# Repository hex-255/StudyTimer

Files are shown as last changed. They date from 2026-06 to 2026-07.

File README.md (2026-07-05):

# StudyTimer
study timer with neopixel feedback and adaptive break time calculation

study for amount of time you decide and get break time allotted accordingly. 

break time = time studied divided by 5

formfactor inspired by [Adafruit NeoPixel rotary fidget](https://learn.adafruit.com/neopixel-rotary-fidget/overview) 

Check out the the [Instructables article](https://www.instructables.com/MagSafe-StudyTimer-Makes-Studying-3-More-Enjoyable/) for an in-depth build guide.

## Features
- Neopixel visual feedback (one pixel equals 2.5 minutes of study time or 1 minute of breaktime)
- Adaptive break time calculation
- Audio feedback with mini speaker
- interface through [Adafruit ANO Rotary Encoder](https://learn.adafruit.com/ano-rotary-encoder)



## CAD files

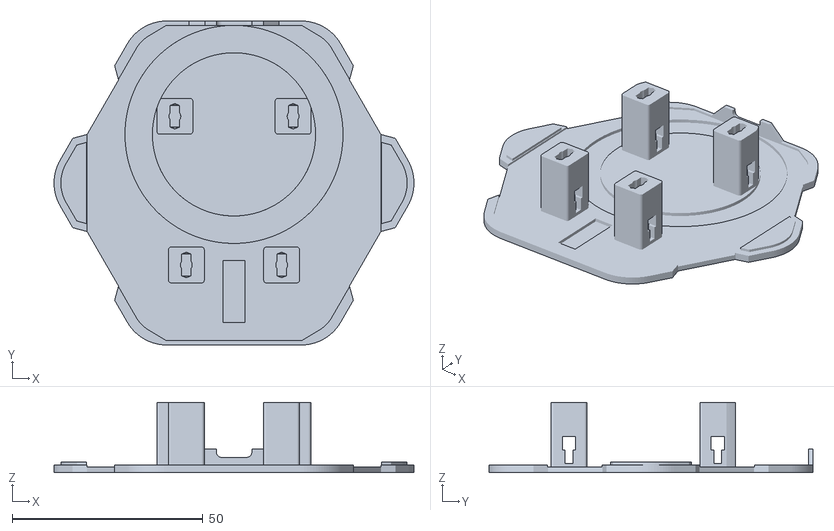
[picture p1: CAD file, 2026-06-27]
STL_files/Bottom.stl
94.4 x 85.0 x 18.4

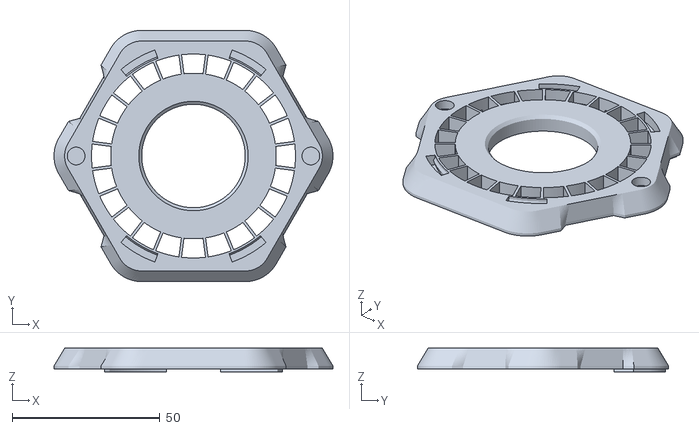
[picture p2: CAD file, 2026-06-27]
STL_files/Top.stl
94.4 x 85.0 x 8.00

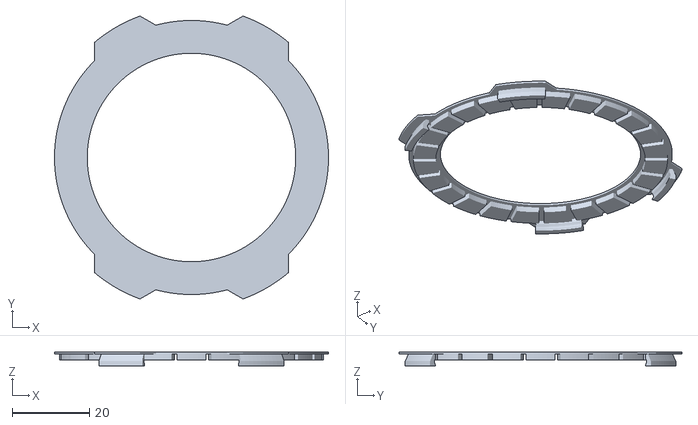
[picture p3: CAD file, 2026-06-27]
STL_files/Diffuser.stl
71.0 x 73.3 x 3.50

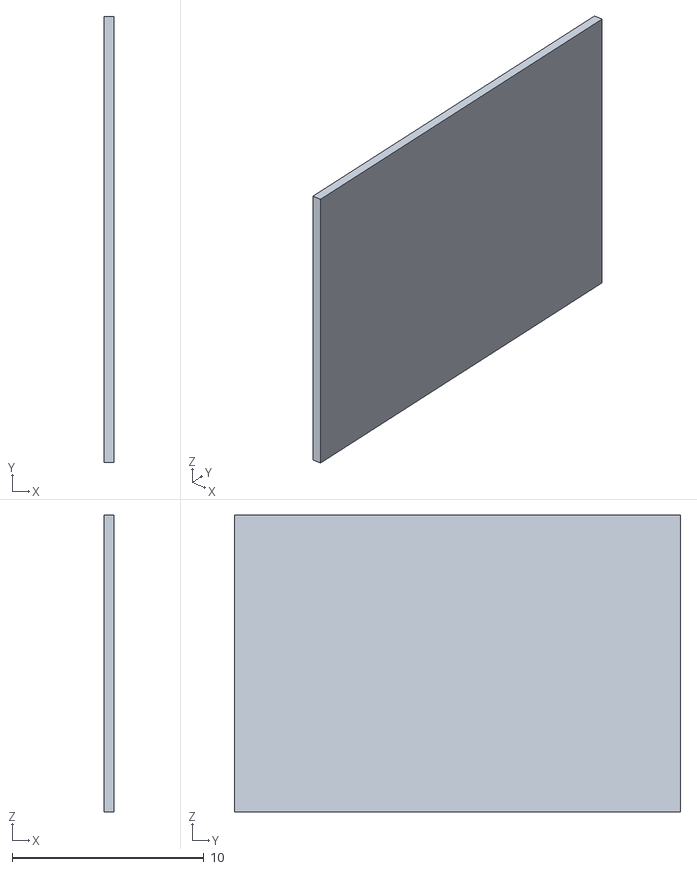
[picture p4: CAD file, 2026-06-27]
STL_files/Streak_Cover_Flat.stl
0.5 x 23.3 x 15.5

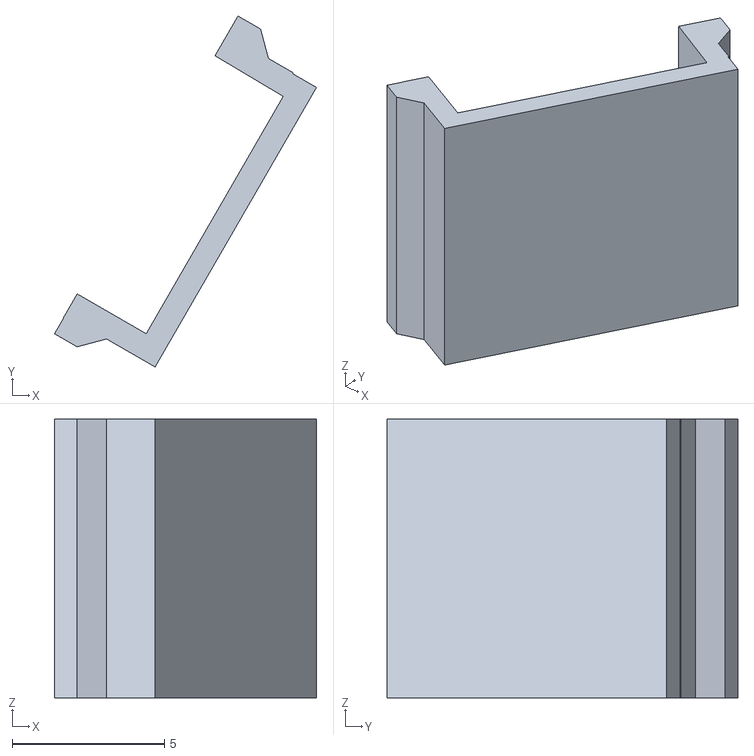
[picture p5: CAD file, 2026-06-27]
STL_files/SlideSwitch_White.stl
8.60 x 11.5 x 9.15

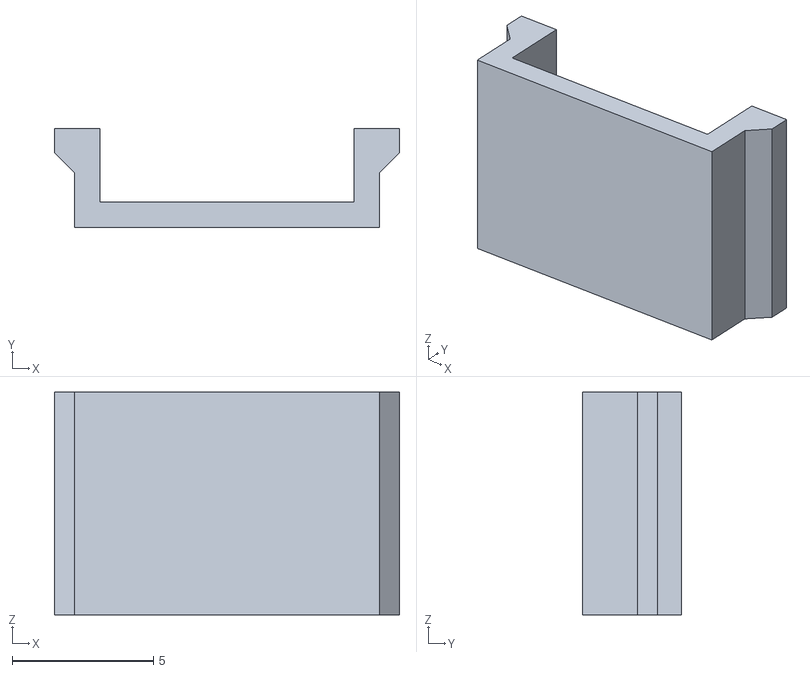
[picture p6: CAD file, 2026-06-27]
STL_files/Magnet_White.stl
12.2 x 3.51 x 7.89

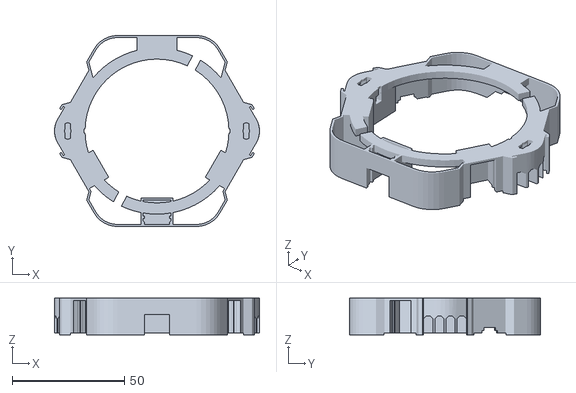
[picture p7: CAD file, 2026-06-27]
STL_files/Middle.stl
91.2 x 85.0 x 16.4

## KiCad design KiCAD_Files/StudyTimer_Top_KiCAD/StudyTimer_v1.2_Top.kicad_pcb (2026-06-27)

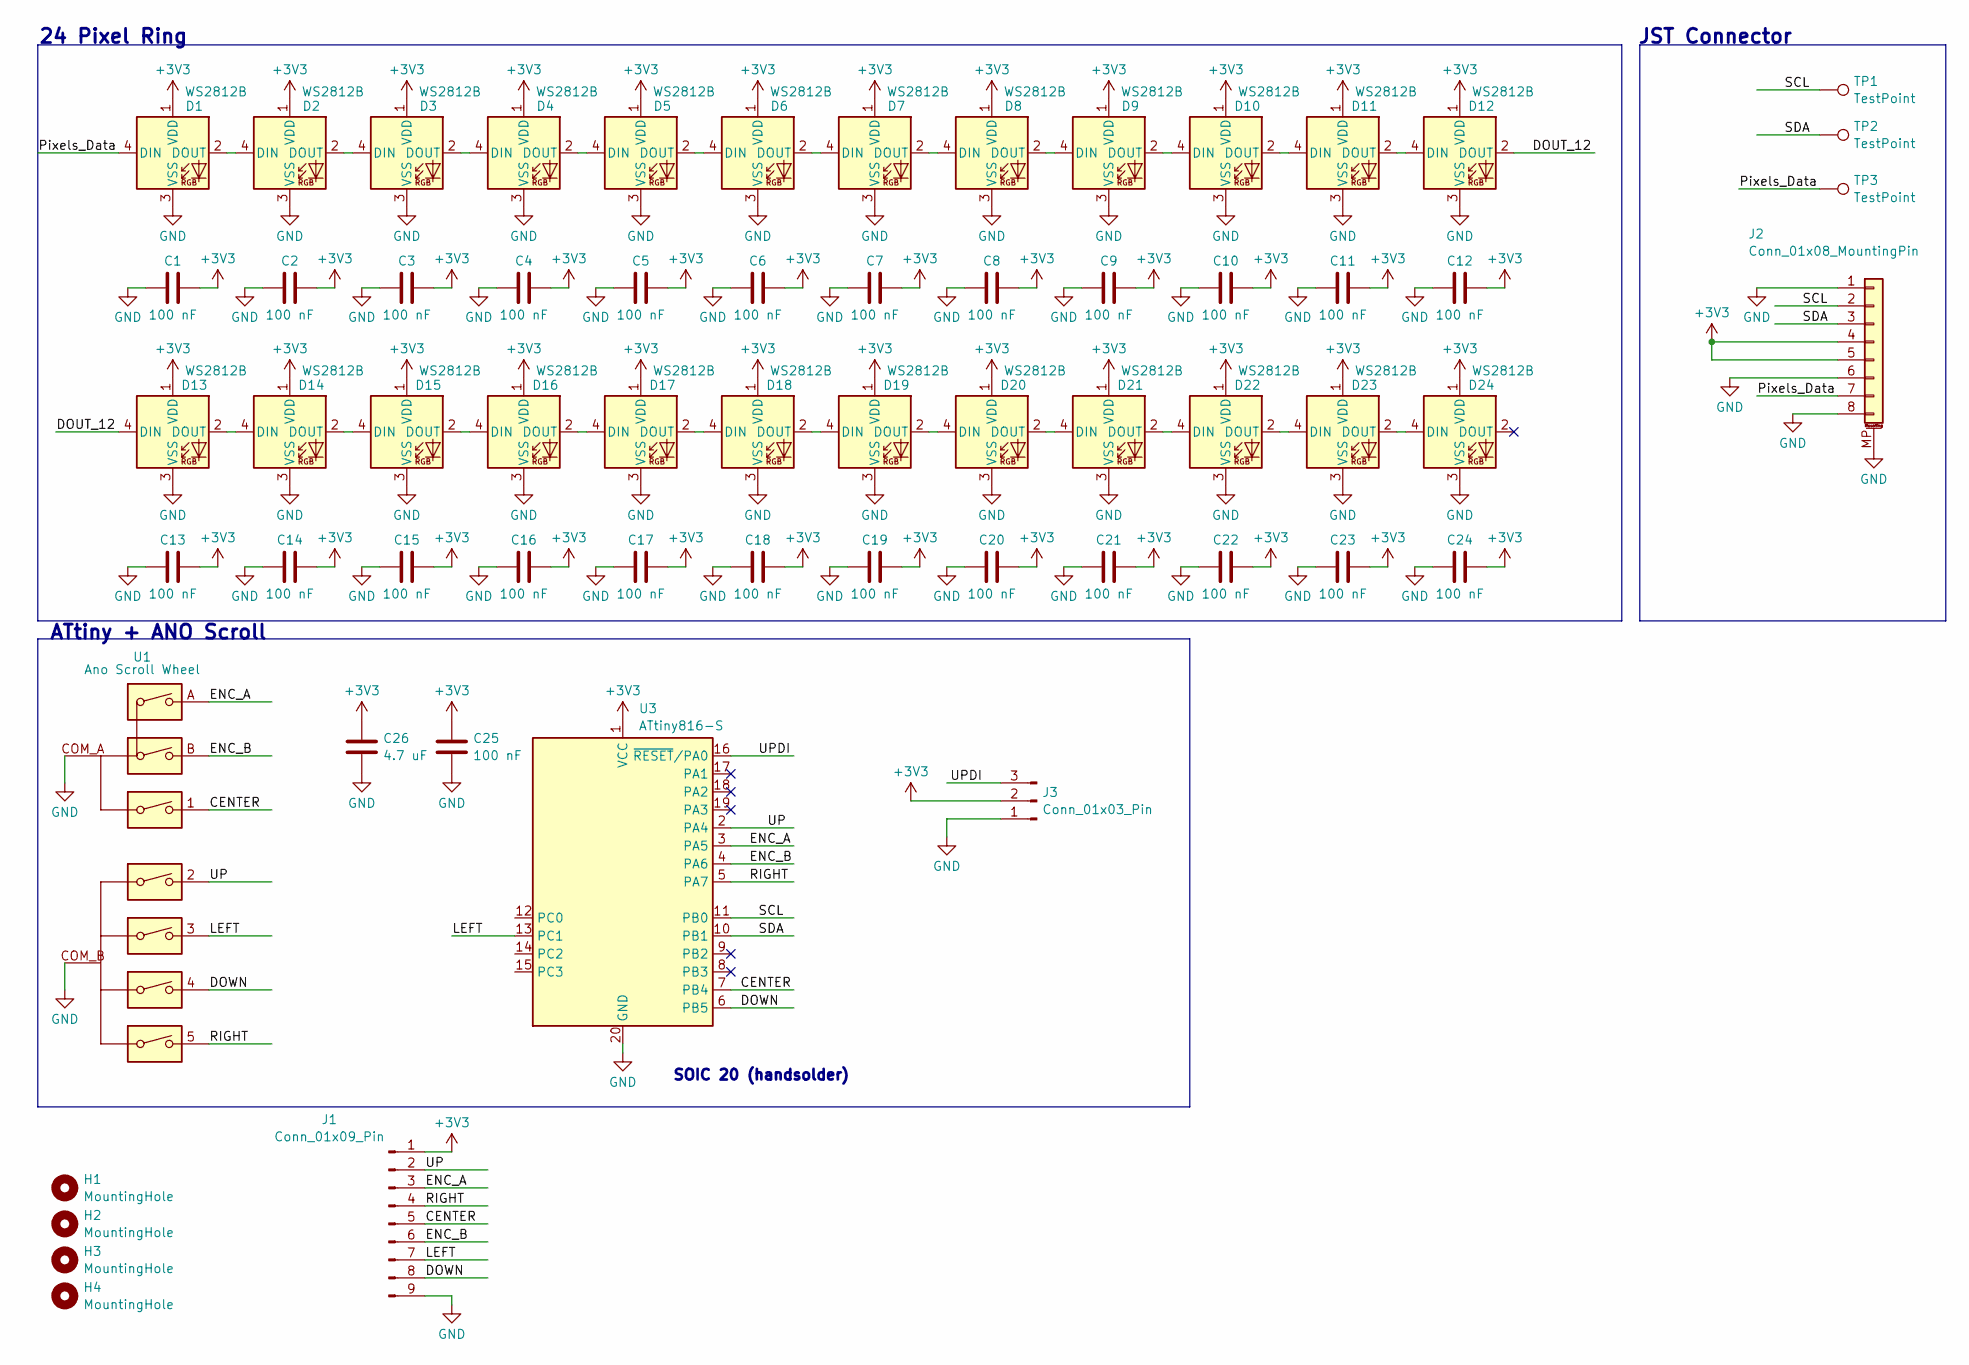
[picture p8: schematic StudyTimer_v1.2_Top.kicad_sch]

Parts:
C1, C2, C3, C4, C5, C6, C7, C8, C9, C10, C11, C12, C13, C14, C15, C16, C17, C18, C19, C20, C21, C22, C23, C24, C25: 100 nF; C_0805_2012Metric_Pad1.18x1.45mm_HandSolder
C26: 4.7 uF; C_0805_2012Metric_Pad1.18x1.45mm_HandSolder
D1: WS2812B; LED_WS2812B_PLCC4_5.0x5.0mm_P3.2mm_edited; Manufacturer_Part_Number 3094
D2, D3, D4, D5, D6, D7, D8, D9, D10, D11, D12, D13, D14, D15, D16, D17, D18, D19, D20, D21, D22, D23, D24: WS2812B; LED_WS2812B_PLCC4_5.0x5.0mm_P3.2mm_edited
H1, H2, H3, H4: MountingHole; MountingHole_3.2mm_M3
J1: Conn_01x09_Pin; PinHeader_1x09_P2.54mm_Vertical
J2: Conn_01x08_MountingPin; SM08BSRSSTBLFSN_1mm_8Pin; Manufacturer_Part_Number SM08B-SRSS-TB
J3: Conn_01x03_Pin; PinHeader_1x03_P2.54mm_Vertical
TP1, TP2, TP3: TestPoint; TestPoint_THTPad_D2.0mm_Drill1.0mm
U1: Ano Scroll Wheel; ANO Scroll Wheel; Manufacturer_Part_Number 5001
U3: ATtiny816-S; SOIC-20W_7.5x12.8mm_P1.27mm; Manufacturer_Part_Number ATTINY816-SNR

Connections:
+3V3: C1.2, C2.2, C3.2, C4.2, C5.2, C6.2, C7.2, C8.2, C9.2, C10.2, C11.2, C12.2, C13.2, C14.2, C15.2, C16.2, C17.2, C18.2, C19.2, C20.2, C21.2, C22.2, C23.2, C24.2, C25.1, C26.1, D1.1 (VDD), D2.1 (VDD), D3.1 (VDD), D4.1 (VDD), D5.1 (VDD), D6.1 (VDD), D7.1 (VDD), D8.1 (VDD), D9.1 (VDD), D10.1 (VDD), D11.1 (VDD), D12.1 (VDD), D13.1 (VDD), D14.1 (VDD), D15.1 (VDD), D16.1 (VDD), D17.1 (VDD), D18.1 (VDD), D19.1 (VDD), D20.1 (VDD), D21.1 (VDD), D22.1 (VDD), D23.1 (VDD), D24.1 (VDD), J1.1, J2.4, J2.5, J3.2, U3.1 (VCC)
/CENTER: J1.5, U1.1, U3.7 (PB4)
/DOUT_12: D12.2 (DOUT), D13.4 (DIN)
/DOWN: J1.8, U1.4, U3.6 (PB5)
/ENC_A: J1.3, U1.A, U3.3 (PA5)
/ENC_B: J1.6, U1.B, U3.4 (PA6)
/LEFT: J1.7, U1.3, U3.13 (PC1)
/Pixels_Data: D1.4 (DIN), J2.7, TP3.1
/RIGHT: J1.4, U1.5, U3.5 (PA7)
/SCL: J2.2, TP1.1, U3.11 (PB0)
/SDA: J2.3, TP2.1, U3.10 (PB1)
/UP: J1.2, U1.2, U3.2 (PA4)
/UPDI: J3.3, U3.16 (~RESET/PA0)
GND: C1.1, C2.1, C3.1, C4.1, C5.1, C6.1, C7.1, C8.1, C9.1, C10.1, C11.1, C12.1, C13.1, C14.1, C15.1, C16.1, C17.1, C18.1, C19.1, C20.1, C21.1, C22.1, C23.1, C24.1, C25.2, C26.2, D1.3 (VSS), D2.3 (VSS), D3.3 (VSS), D4.3 (VSS), D5.3 (VSS), D6.3 (VSS), D7.3 (VSS), D8.3 (VSS), D9.3 (VSS), D10.3 (VSS), D11.3 (VSS), D12.3 (VSS), D13.3 (VSS), D14.3 (VSS), D15.3 (VSS), D16.3 (VSS), D17.3 (VSS), D18.3 (VSS), D19.3 (VSS), D20.3 (VSS), D21.3 (VSS), D22.3 (VSS), D23.3 (VSS), D24.3 (VSS), J1.9, J2.1, J2.6, J2.8, J2.MP (MountPin), J3.1, U1.COM_A, U1.COM_B, U3.20 (GND)
unnamed: D1.2 (DOUT), D2.4 (DIN)
unnamed: D2.2 (DOUT), D3.4 (DIN)
unnamed: D3.2 (DOUT), D4.4 (DIN)
unnamed: D4.2 (DOUT), D5.4 (DIN)
unnamed: D5.2 (DOUT), D6.4 (DIN)
unnamed: D6.2 (DOUT), D7.4 (DIN)
unnamed: D7.2 (DOUT), D8.4 (DIN)
unnamed: D8.2 (DOUT), D9.4 (DIN)
unnamed: D9.2 (DOUT), D10.4 (DIN)
unnamed: D10.2 (DOUT), D11.4 (DIN)
unnamed: D11.2 (DOUT), D12.4 (DIN)
unnamed: D13.2 (DOUT), D14.4 (DIN)
unnamed: D14.2 (DOUT), D15.4 (DIN)
unnamed: D15.2 (DOUT), D16.4 (DIN)
unnamed: D16.2 (DOUT), D17.4 (DIN)
unnamed: D17.2 (DOUT), D18.4 (DIN)
unnamed: D18.2 (DOUT), D19.4 (DIN)
unnamed: D19.2 (DOUT), D20.4 (DIN)
unnamed: D20.2 (DOUT), D21.4 (DIN)
unnamed: D21.2 (DOUT), D22.4 (DIN)
unnamed: D22.2 (DOUT), D23.4 (DIN)
unnamed: D23.2 (DOUT), D24.4 (DIN)

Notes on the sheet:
ATtiny + ANO Scroll
JST Connector
SOIC 20 (handsolder)
24 Pixel Ring

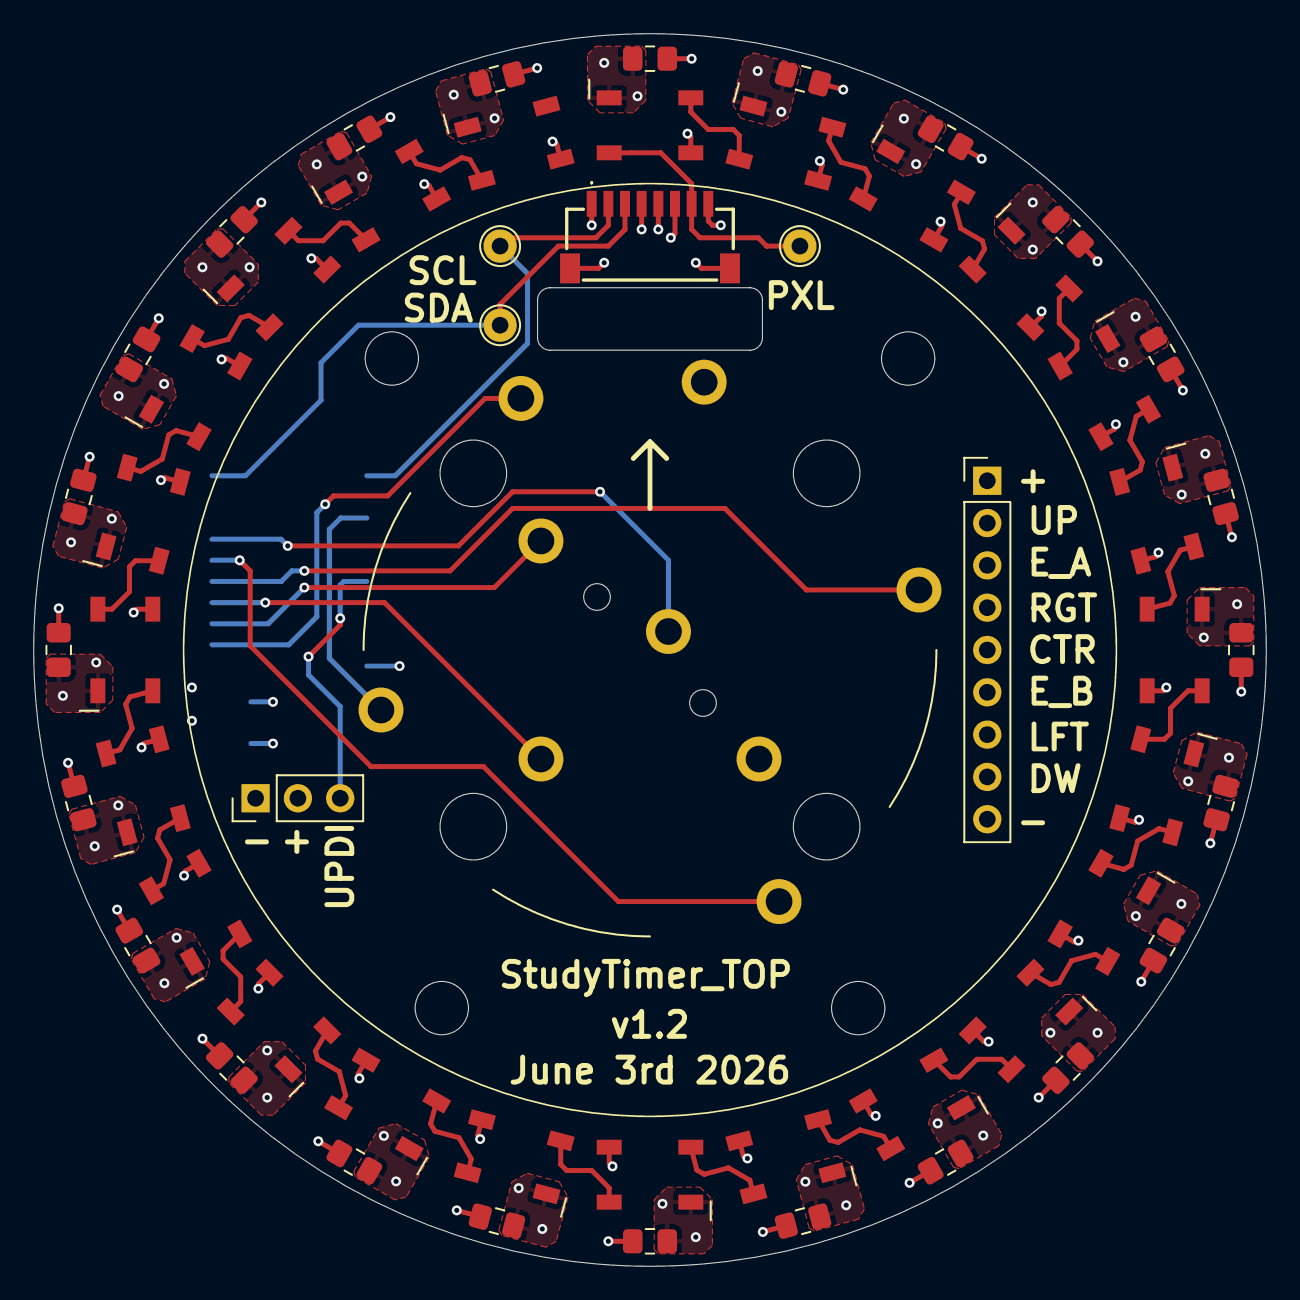
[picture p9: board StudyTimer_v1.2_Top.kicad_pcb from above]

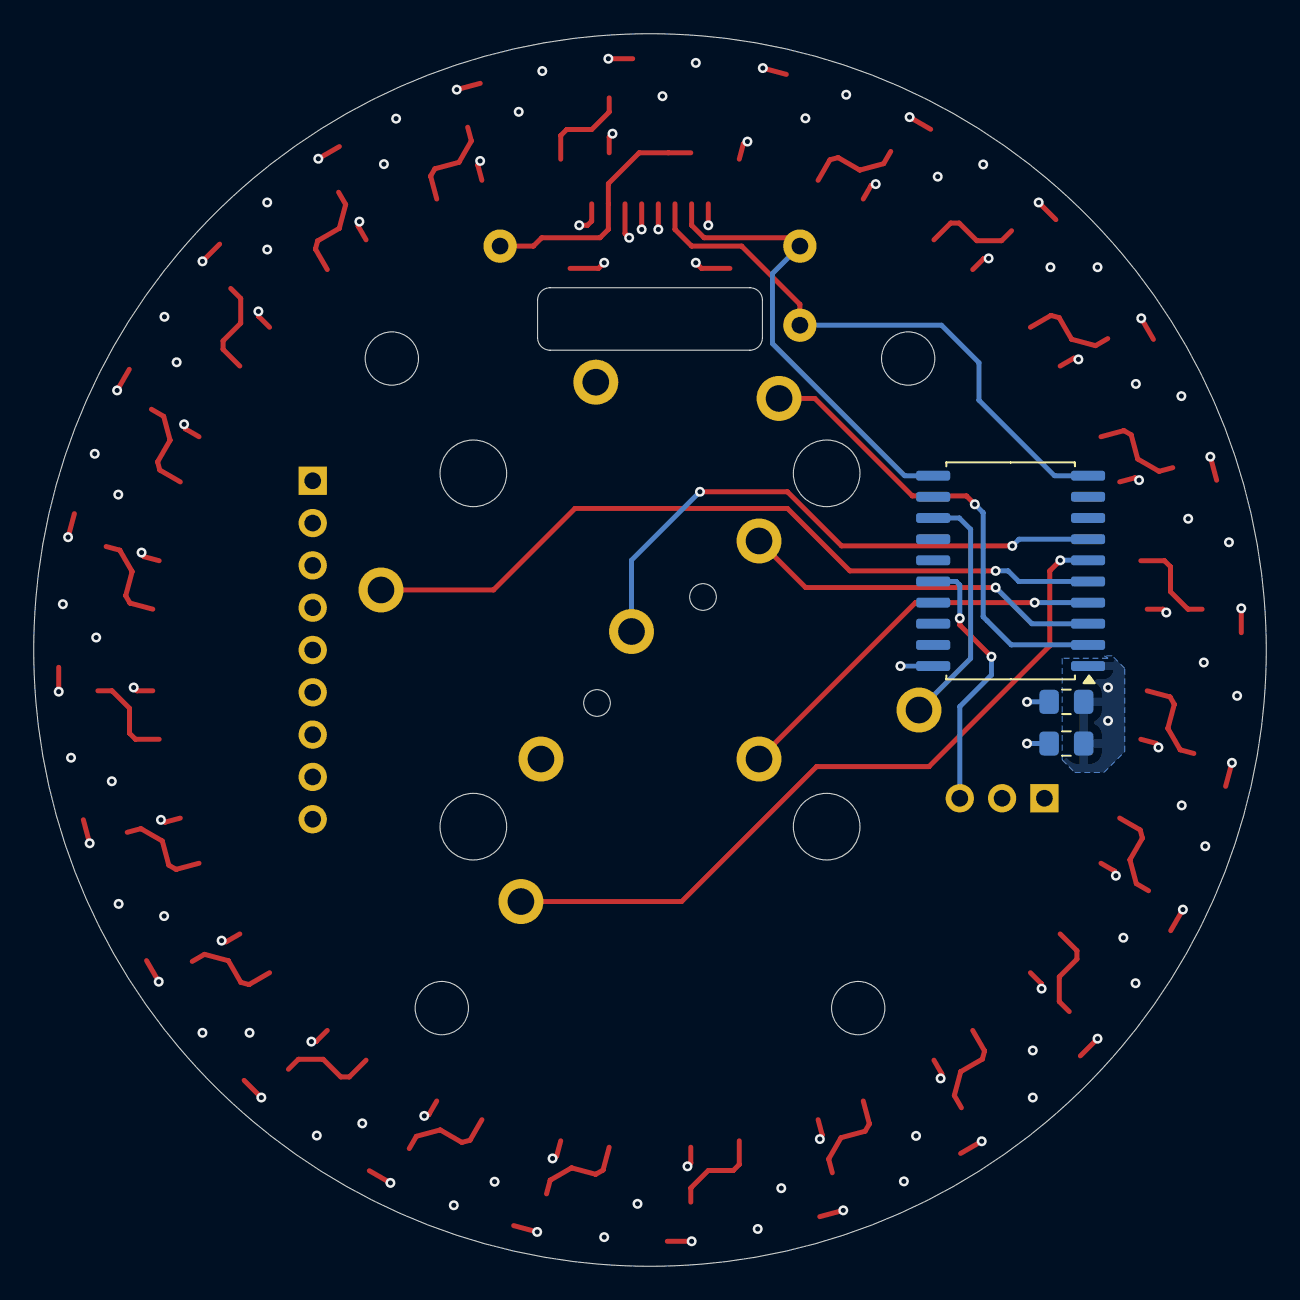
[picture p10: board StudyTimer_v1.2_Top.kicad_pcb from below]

Board: 4 copper layers, 74.0 x 74.0 mm, 62 parts (3 on the bottom side), 36 nets.

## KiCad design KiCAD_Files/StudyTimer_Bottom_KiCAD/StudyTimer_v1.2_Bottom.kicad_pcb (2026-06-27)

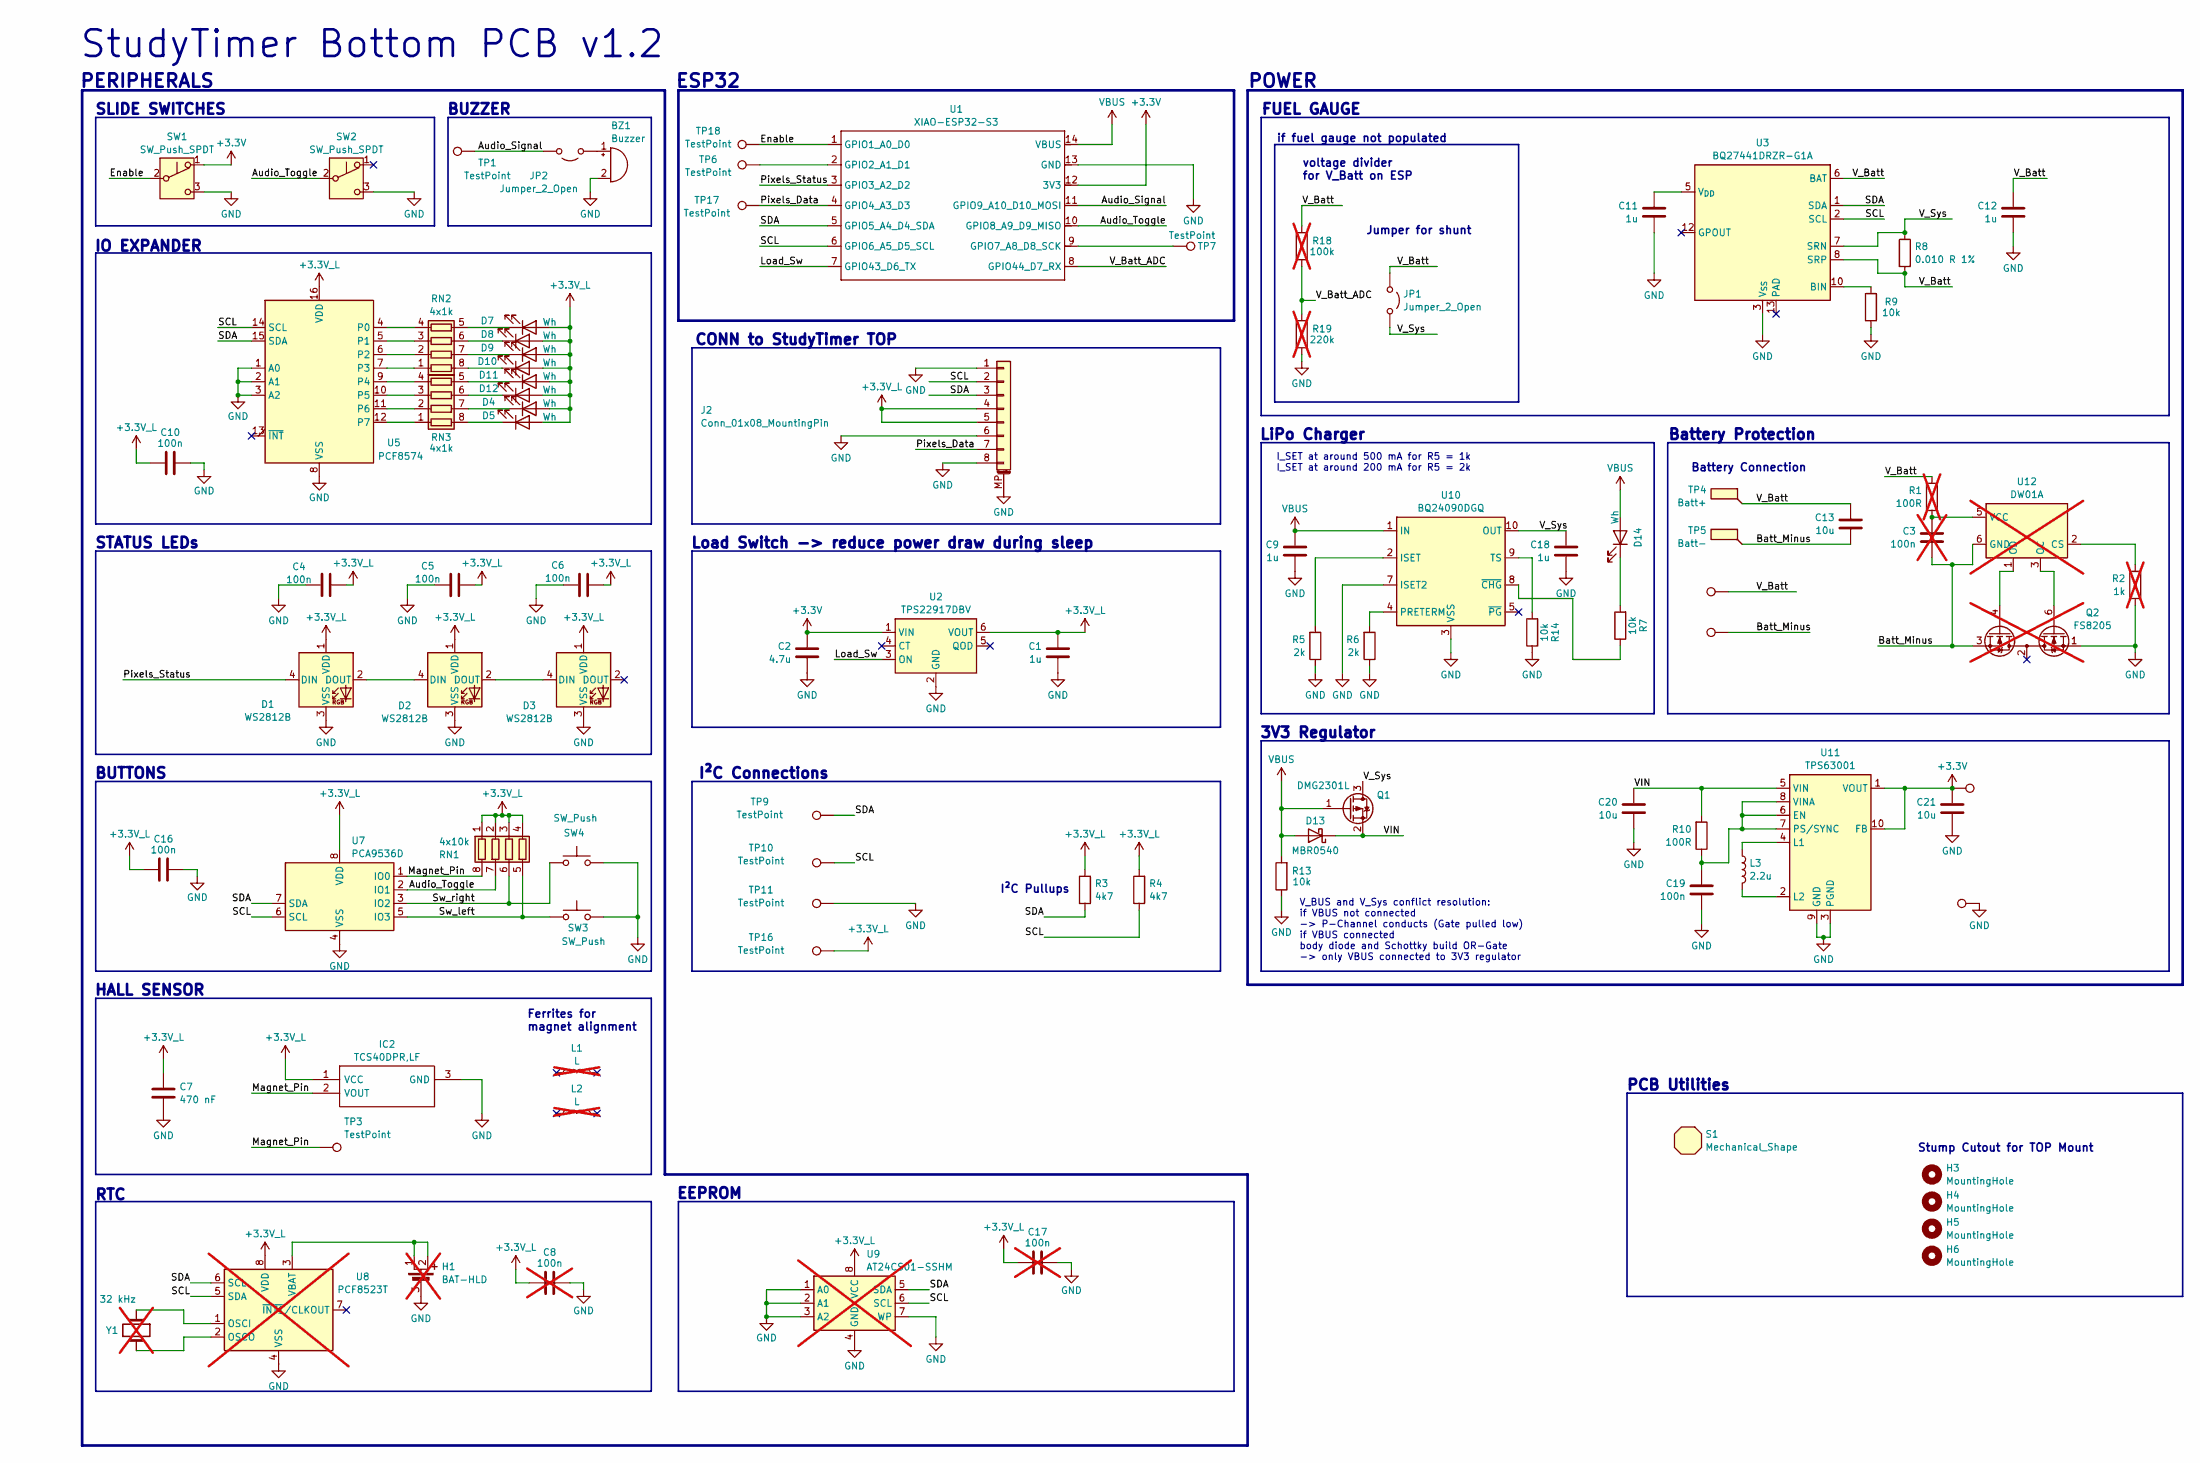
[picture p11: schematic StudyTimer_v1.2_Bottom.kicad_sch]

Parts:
BZ1: Buzzer; Buzzer_CUI_CPT-9019S-SMT; Manufacturer_Part_Number CPT-9019S-SMT-TR
C1, C9, C11, C12, C18: 1u; C_0805_2012Metric_Pad1.18x1.45mm_HandSolder
C2: 4.7u; C_0805_2012Metric_Pad1.18x1.45mm_HandSolder
C3, C8, C17: 100n; C_0805_2012Metric_Pad1.18x1.45mm_HandSolder; not fitted
C4, C5, C6, C10, C16, C19: 100n; C_0805_2012Metric_Pad1.18x1.45mm_HandSolder
C7: 470 nF; C_0805_2012Metric_Pad1.18x1.45mm_HandSolder
C13, C20, C21: 10u; C_0805_2012Metric_Pad1.18x1.45mm_HandSolder
D1, D2, D3: WS2812B; LED_WS2812B_PLCC4_5.0x5.0mm_P3.2mm
D4, D5, D8, D9, D10, D11, D12, D14: Wh; LED_0805_2012Metric_Pad1.15x1.40mm_HandSolder
D7: Wh; LED_0805_2012Metric_Pad1.15x1.40mm_HandSolder; Manufacturer_Part_Number IN-S85AT5UW
D13: MBR0540; D_SOD-123
H1: BAT-HLD; BATHLD007SMTTR; Manufacturer_Part_Number BAT-HLD-003-SMT; Mouser Part Number 712-BAT-HLD-003-SMT; not fitted
H3, H4, H5, H6: MountingHole; StudyTimer_Stump_Cutout
IC2: TCS40DPR,LF; SOTFL95P240X88-3N; Manufacturer_Part_Number TCS40DPR,LF; Mouser Part Number 757-TCS40DPRLF
J2: Conn_01x08_MountingPin; BM08BSRSSTBLFSN; Manufacturer_Part_Number BQ27441DRZR-G1A
JP1, JP2: Jumper_2_Open; SolderJumper-2_P1.3mm_Open_TrianglePad1.0x1.5mm
L1, L2: L; INDPM4341X80N; not fitted
L3: 2.2u; L_1008_2520Metric_Pad1.43x2.20mm_HandSolder
Q1: DMG2301L; SOT-23
Q2: FS8205; SOT-23-6; not fitted
R1: 100R; R_0805_2012Metric_Pad1.20x1.40mm_HandSolder; not fitted
R2: 1k; R_0805_2012Metric_Pad1.20x1.40mm_HandSolder; not fitted
R3, R4: 4k7; R_0805_2012Metric_Pad1.20x1.40mm_HandSolder
R5, R6: 2k; R_0805_2012Metric_Pad1.20x1.40mm_HandSolder
R7, R9, R13, R14: 10k; R_0805_2012Metric_Pad1.20x1.40mm_HandSolder
R8: 0.010 R 1%; R_0805_2012Metric_Pad1.20x1.40mm_HandSolder; Manufacturer_Part_Number CRF0805-FZ-R010ELF
R10: 100R; R_0805_2012Metric_Pad1.20x1.40mm_HandSolder
R18: 100k; R_0805_2012Metric_Pad1.20x1.40mm_HandSolder; not fitted
R19: 220k; R_0805_2012Metric_Pad1.20x1.40mm_HandSolder; not fitted
RN1: 4x10k; R_Array_Convex_4x0612; Manufacturer_Part_Number ACASA100221002P100
RN2, RN3: 4x1k; R_Array_Convex_4x0612; Manufacturer_Part_Number ACASA100121001P100
S1: Mechanical_Shape; Outline_StudyTimer_v1.2
SW1, SW2: SW_Push_SPDT; SS12SDH2; Manufacturer_Part_Number SS12SDH2
SW3: SW_Push; KSS341G LFS
SW4: SW_Push; KSS341G LFS; Manufacturer_Part_Number KSS341G LFS
TP1, TP2, TP6, TP7, TP9, TP10, TP11, TP12, TP16, TP17, TP18: TestPoint; TestPoint_THTPad_D2.0mm_Drill1.0mm
TP3: TestPoint; TestPoint_Pad_2.0x2.0mm
TP4: Batt+; TestPoint_Pad_2.5x2.5mm
TP5: Batt-; TestPoint_Pad_2.5x2.5mm
TP14, TP21: TestPoint; TestPoint_THTPad_D1.5mm_Drill0.7mm
U1: XIAO-ESP32-S3; XIAO-ESP32-S3-SMD; Manufacturer_Part_Number 113991114
U2: TPS22917DBV; SOT-23-6; Manufacturer_Part_Number TPS22917DBVT
U3: BQ27441DRZR-G1A; Texas_S-PDSO-N12; Manufacturer_Part_Number BQ27441DRZR-G1A
U5: PCF8574; SOIC-16W_7.5x10.3mm_P1.27mm; Manufacturer_Part_Number PCF8574ADWR
U7: PCA9536D; SOIC-8_3.9x4.9mm_P1.27mm; Manufacturer_Part_Number PCA9536DR
U8: PCF8523T; SOIC-8_3.9x4.9mm_P1.27mm; not fitted
U9: AT24CS01-SSHM; SOIC-8_3.9x4.9mm_P1.27mm; not fitted
U10: BQ24090DGQ; HVSSOP-10-1EP_3x3mm_P0.5mm_EP1.83x1.89mm_ThermalVias; Manufacturer_Part_Number BQ24090DGQT
U11: TPS63001; Texas_DRC0010J_ThermalVias; Manufacturer_Part_Number TPS63001DRCR
U12: DW01A; SOT-23-6; not fitted
Y1: 32 kHz; ABS2532768KHZT; not fitted

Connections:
+3.3V: C2.2, C21.2, SW1.1 (A), TP21.1, U1.12 (3V3), U2.1 (VIN), U11.1 (VOUT), U11.10 (FB)
+3.3V_L: C1.2, C4.2, C5.2, C6.2, C7.1, C8.1, C10.1, C16.1, C17.1, D1.1 (VDD), D2.1 (VDD), D3.1 (VDD), D4.2 (A), D5.2 (A), D7.2 (A), D8.2 (A), D9.2 (A), D10.2 (A), D11.2 (A), D12.2 (A), IC2.1 (VCC), J2.4, J2.5, R3.2, R4.2, RN1.1 (R1.1), RN1.2 (R2.1), RN1.3 (R3.1), RN1.4 (R4.1), TP16.1, U2.6 (VOUT), U5.16 (VDD), U7.8 (VDD), U8.8 (VDD), U9.8 (VCC)
/Audio_Signal: JP2.2 (B), TP1.1, U1.11 (GPIO9_A10_D10_MOSI)
/Audio_Toggle: RN1.7 (R2.2), SW2.2 (B), U1.10 (GPIO8_A9_D9_MISO), U7.2 (IO1)
/Batt_Minus: C3.1, C13.1, Q2.3 (S2), TP5.1, TP12.1, U12.6 (GND)
/Enable: SW1.2 (B), TP18.1, U1.1 (GPIO1_A0_D0)
/Load_Sw: U1.7 (GPIO43_D6_TX), U2.3 (ON)
/Magnet_Pin: IC2.2 (VOUT), RN1.8 (R1.2), TP3.1, U7.1 (IO0)
/Pixels_Data: J2.7, TP17.1, U1.4 (GPIO4_A3_D3)
/Pixels_Status: D1.4 (DIN), U1.3 (GPIO3_A2_D2)
/SCL: J2.2, R4.1, TP10.1, U1.6 (GPIO6_A5_D5_SCL), U3.2 (SCL), U5.14 (SCL), U7.6 (SCL), U8.5 (SDA), U9.6 (SCL)
/SDA: J2.3, R3.1, TP9.1, U1.5 (GPIO5_A4_D4_SDA), U3.1 (SDA), U5.15 (SDA), U7.7 (SDA), U8.6 (SCL), U9.5 (SDA)
/Sw_left: RN1.5 (R4.2), SW3.1, U7.5 (IO3)
/Sw_right: RN1.6 (R3.2), SW4.1, U7.3 (IO2)
/VIN: C20.2, D13.1 (K), Q1.2 (S), R10.2, U11.5 (VIN)
/V_Batt: C12.2, C13.2, JP1.1 (A), R1.2, R8.2, R18.2, TP2.1, TP4.1, U3.6 (BAT), U3.8 (SRP)
/V_Batt_ADC: R18.1, R19.2, U1.8 (GPIO44_D7_RX)
/V_Sys: C18.2, JP1.2 (B), Q1.3 (D), R8.1, U3.7 (SRN), U10.10 (OUT)
GND: BZ1.2 (-), C1.1, C2.1, C4.1, C5.1, C6.1, C7.2, C8.2, C9.1, C10.2, C11.1, C12.1, C16.2, C17.2, C18.1, C19.1, C20.1, C21.1, D1.3 (VSS), D2.3 (VSS), D3.3 (VSS), H1.3, IC2.3 (GND), J2.1, J2.6, J2.8, J2.MP (MountPin), Q2.1 (D1), R2.1, R5.1, R6.1, R9.1, R13.1, R14.1, R19.1, SW1.3 (C), SW2.3 (C), SW3.2, SW4.2, TP11.1, TP14.1, U1.13 (GND), U2.2 (GND), U3.3 (V_{SS}), U5.1 (A0), U5.2 (A1), U5.3 (A2), U5.8 (VSS), U7.4 (VSS), U8.4 (VSS), U9.1 (A0), U9.2 (A1), U9.3 (A2), U9.4 (GND), U9.7 (WP), U10.3 (VSS), U10.7 (ISET2), U10.11 (VSS), U11.3 (PGND), U11.9 (GND), U11.11 (PGND); also elsewhere on the board
unnamed: BZ1.1 (+), JP2.1 (A)
unnamed: D1.2 (DOUT), D2.4 (DIN)
unnamed: D2.2 (DOUT), D3.4 (DIN)
unnamed: D4.1 (K), RN3.7 (R2.2)
unnamed: D5.1 (K), RN3.8 (R1.2)
unnamed: D7.1 (K), RN2.5 (R4.2)
unnamed: D8.1 (K), RN2.6 (R3.2)
unnamed: D9.1 (K), RN2.7 (R2.2)
unnamed: D10.1 (K), RN2.8 (R1.2)
unnamed: D11.1 (K), RN3.5 (R4.2)
unnamed: D12.1 (K), RN3.6 (R3.2)
unnamed: D14.1 (K), R7.2
unnamed: Q2.6 (G1), U12.3 (OC)
unnamed: Q2.4 (G2), U12.1 (OD)
unnamed: RN2.1 (R1.1), U5.7 (P3)
unnamed: RN2.2 (R2.1), U5.6 (P2)
unnamed: RN2.3 (R3.1), U5.5 (P1)
unnamed: RN2.4 (R4.1), U5.4 (P0)
unnamed: RN3.1 (R1.1), U5.12 (P7)
unnamed: RN3.2 (R2.1), U5.11 (P6)
unnamed: RN3.3 (R3.1), U5.10 (P5)
unnamed: RN3.4 (R4.1), U5.9 (P4)
unnamed: TP6.1, U1.2 (GPIO2_A1_D1)
unnamed: TP7.1, U1.9 (GPIO7_A8_D8_SCK)
unnamed: R9.2, U3.10 (BIN)
unnamed: C11.2, U3.5 (V_{DD})
unnamed: U8.1 (OSCI), Y1.1
unnamed: U8.2 (OSCO), Y1.2
unnamed: H1.1, H1.2, U8.3 (VBAT)
unnamed: R5.2, U10.2 (ISET)
unnamed: R6.2, U10.4 (PRETERM)
unnamed: R14.2, U10.9 (TS)
unnamed: R7.1, U10.8 (~CHG)
unnamed: C19.2, R10.1, U11.6 (EN), U11.7 (PS/SYNC), U11.8 (VINA)
unnamed: L3.1, U11.4 (L1)
unnamed: L3.2, U11.2 (L2)
unnamed: R2.2, U12.2 (CS)
unnamed: C3.2, R1.1, U12.5 (VCC)
VBUS: C9.2, D13.2 (A), D14.2 (A), Q1.1 (G), R13.2, U1.14 (VBUS), U10.1 (IN)

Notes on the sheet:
IO EXPANDER
I²C Pullups
BUTTONS
Battery Connection
PERIPHERALS
Ferrites for magnet alignment
I_SET at around 500 mA for R5 = 1k I_SET at around 200 mA for R5 = 2k
ESP32
FUEL GAUGE
Load Switch -> reduce power draw during sleep
Battery Protection
if fuel gauge not populated
voltage divider for V_Batt on ESP
RTC
POWER
LiPo Charger
PCB Utilities
3V3 Regulator
EEPROM
STATUS LEDs
StudyTimer Bottom PCB v1.2
HALL SENSOR
V_BUS and V_Sys conflict resolution: if VBUS not connected -> P-Channel conducts (Gate pulled low) if VBUS connected body diode and Schottky build OR-Gate -> only VBUS connected to 3V3 regulator
Stump Cutout for TOP Mount
Jumper for shunt
I²C Connections
SLIDE SWITCHES
BUZZER
CONN to StudyTimer TOP

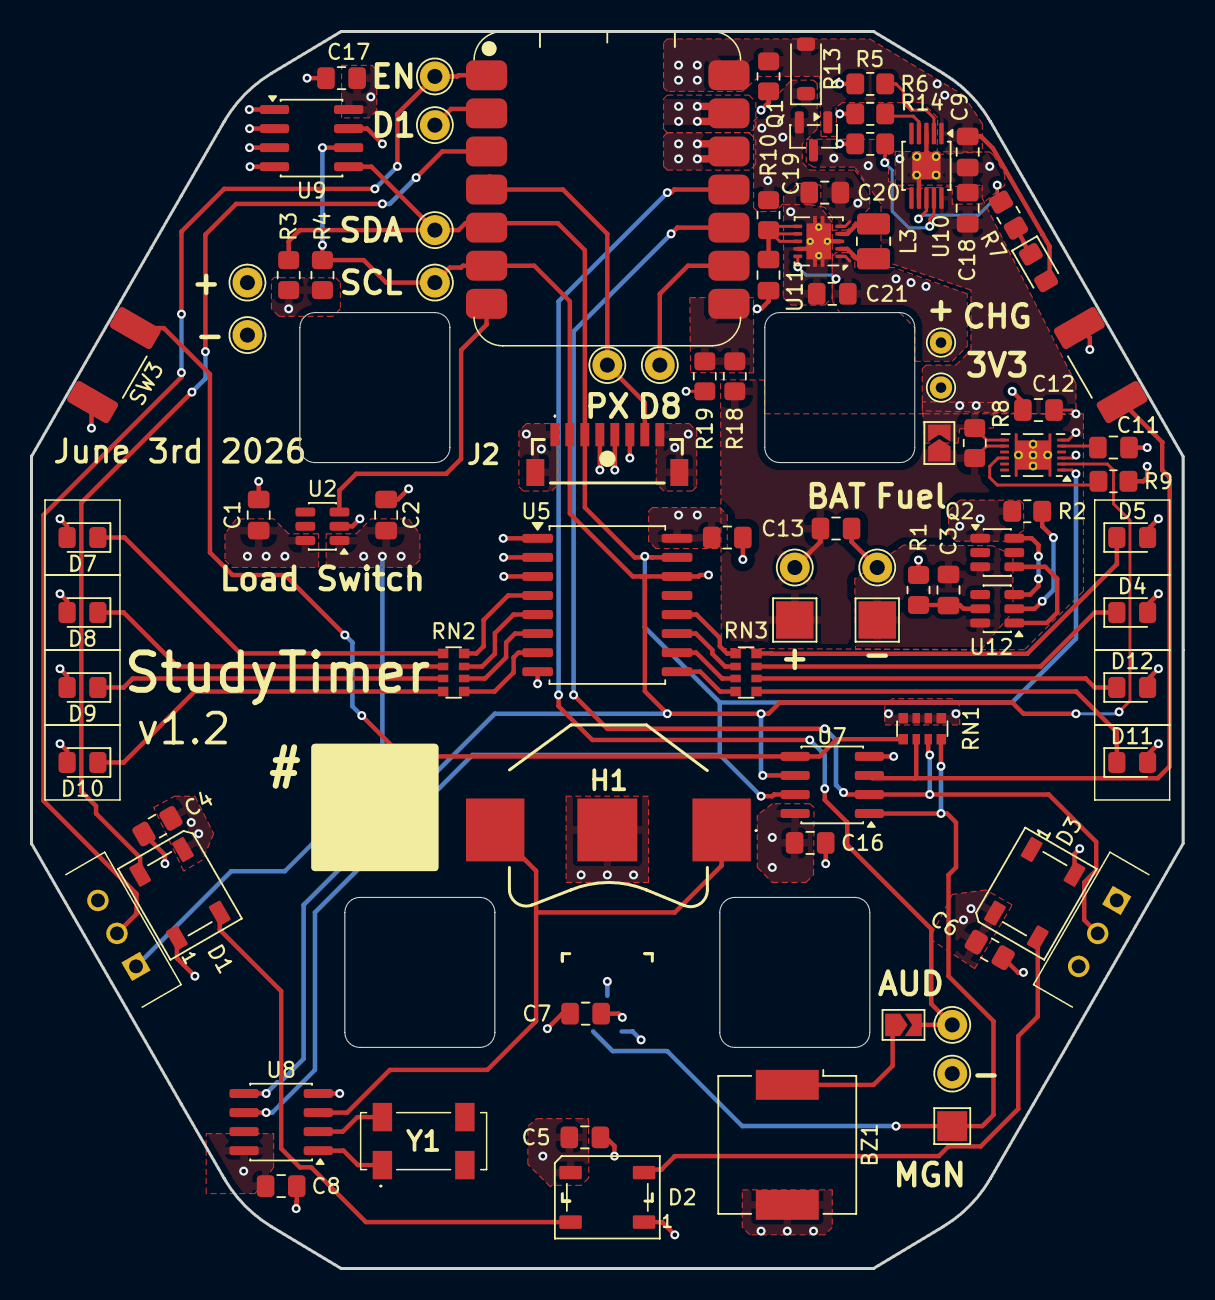
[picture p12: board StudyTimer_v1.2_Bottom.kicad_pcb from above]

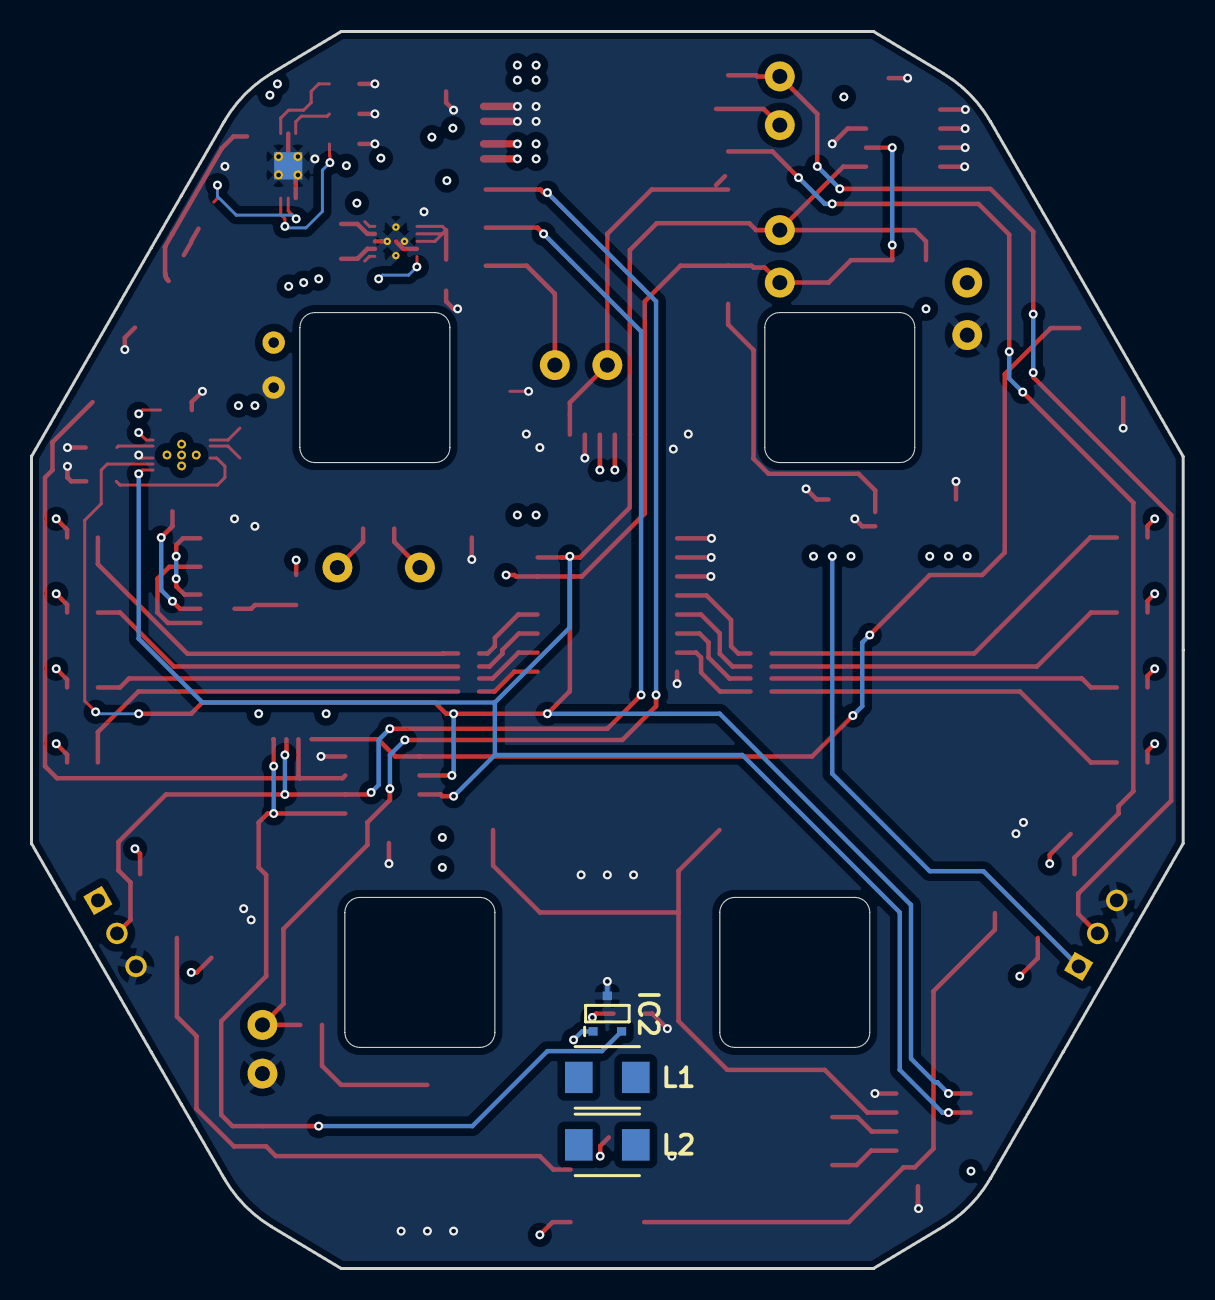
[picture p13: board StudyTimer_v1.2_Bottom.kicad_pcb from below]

Board: 4 copper layers, 76.8 x 82.5 mm, 97 parts (3 on the bottom side), 58 nets.

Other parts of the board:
TP13: TestPoint; TestPoint_THTPad_D2.0mm_Drill1.0mm

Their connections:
GND: TP13.1; also elsewhere on the board

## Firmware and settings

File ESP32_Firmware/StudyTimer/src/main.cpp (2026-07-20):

// main.cpp file

#include "Menu.h"
#include "StudyMode.h" 
#include "defines.h"
#include "BreakMode.h"
#include "Config_Menus.h"
#include "StartUp.h"
#include "BreakOverflow.h"
#include "FuelGauge.h"

#include "driver/rtc_io.h"

#include <Preferences.h>

Preferences preferences;



// Define globals here (only once)
CRGB leds[NUM_LEDS];
CRGB status_leds[NUM_LEDS_STATUS];
Adafruit_seesaw ss;
int32_t encoder_position;

bool magnet_detected = false;
bool audio_enabled = false;
bool right_click = false;
bool left_click = false;

bool Main_Menu_debug = true;
bool Study_Mode_debug = true;
bool Break_Mode_debug = true;
bool Config_Menus_debug = true;
bool Startup_debug = true;
bool Magnet_debug = false;
bool FuelGauge_debug = true;
bool I2C_debug = true;
bool NVM_debug = true;

bool strict_mode = false;

bool streak_enabled = false;

int streak_counter = 0; 

const int TONE_PIN = D10;
const int TONE_CHANNEL = 0;   // LEDC channel 0..15
const int TONE_FREQ = 500;    // default start frequency
const int TONE_RES = 8;       // 8-bit resolution



// ... existing ...

int time_per_block_break = 60;  // Adjust as needed
int break_interval = 0;
int current_led_index = 0;
unsigned long break_start_block_time = 0;
bool break_started = false;

bool breakStartupPlayed = false;

bool enable_status_LED = true;
bool battery_is_high = true;
bool audio_on = false;

bool check_FixedStudy = false;
int FixedStudy_Index = 9;
unsigned long config_blink_start = 0;
bool mode_config_entered = false;

// ... existing colorOptions, etc. ...

int32_t encoder_offset = 0;
int32_t last_position = 0;
unsigned long encoder_last_activity = 0;

bool FuelGauge_available = false;  // Will be set to true if initialization succeeds

// Button state tracking
bool buttonStates[5] = {true, true, true, true, true};  // Assume HIGH initially (INPUT_PULLUP)

// Color options (excluding white and green)
const CRGB colorOptions[] = {
    CRGB::Red,
    CRGB::Orange,
    CRGB::Aqua,
    CRGB::Gold,      // Amber
    CRGB::Purple,
    CRGB::Teal,
    CRGB::Ivory,
    CRGB::Yellow,
    CRGB::Cyan,
    CRGB::Maroon,
    CRGB::Blue,
    CRGB::Sienna,
    CRGB::Magenta
};

const char* colorOptions_strings[] = {
    "Red",
    "Orange",
    "Aqua",
    "Gold",
    "Purple",
    "Teal",
    "Ivory",
    "Yellow",
    "Cyan",
    "Maroon",
    "Blue",
    "Sienna",
    "Magenta"
};



const int numColors = sizeof(colorOptions) / sizeof(colorOptions[0]);
int currentColorIndex = 0;  // Track which color is active

AppState_t currentState = STATE_STARTUP;

int brightness_limit = 20;  // brightness -> will be loaded from NVM 

// ... existing ...

int time_per_block = 150;  // Adjust as needed
int study_counter = 0;
int num_leds_lit = 0;
unsigned long start_block_time = 0;
bool study_started = false;

// Save controller pointers for independent updates
CLEDController* ringController;
CLEDController* statusController;

void readPCA9536(void);

void handleStatusLEDs();

void handle_Sleep();

void handle_NVM();


void setup() {

    esp_sleep_enable_ext0_wakeup(WAKEUP_GPIO, 0);  //1 = High, 0 = Low

    delay(1000);  // Short delay before starting animation

    Serial.begin(115200);
    Wire.begin();  // Initialize I2C for Seesaw

    //pinMode(D6, INPUT_PULLUP);  // D6 on Xiao (GPIO7)
    pinMode(D6, OUTPUT); // Load Switch output pin 
    pinMode(D0, INPUT);  // ohne PULLUP kein Sleep 
    pinMode(D10, OUTPUT); // Audio Signal 
    pinMode(D9, INPUT_PULLUP);  // D9 on Xiao (GPIO8) - for magnet detection

    digitalWrite(D6, HIGH); // Ensure load switch is on
    //digitalWrite(D6, LOW); // Ensure load switch is off

    Serial.println("Hallo ich bin im Setup!!");

    if (!ss.begin(0x49)) {
        Serial.println("Seesaw not found");
    }

    ss.pinMode(CENTER_BUTTON, INPUT_PULLUP);   
    ss.pinMode(RIGHT_BUTTON, INPUT_PULLUP);   
    ss.pinMode(LEFT_BUTTON, INPUT_PULLUP);   
    ss.pinMode(UP_BUTTON, INPUT_PULLUP);   
    ss.pinMode(DOWN_BUTTON, INPUT_PULLUP);   

    encoder_position = ss.getEncoderPosition();
    last_position = 0;
    encoder_last_activity = millis();

    ringController = &FastLED.addLeds<WS2812, LED_PIN, GRB>(leds, NUM_LEDS);
    statusController = &FastLED.addLeds<WS2812, LED_PIN_STATUS, GRB>(status_leds, NUM_LEDS_STATUS);
    FastLED.clear();

    
    handle_NVM(); // Load settings from non-volatile storage

    ledcSetup(TONE_CHANNEL, TONE_FREQ, TONE_RES);
    ledcAttachPin(TONE_PIN, TONE_CHANNEL);
    ledcWrite(TONE_CHANNEL, 0);  // silent at start

    if(initFuelGauge()){
        setFuelGaugeCapacity(1100);  // Set your battery capacity in mAh
        setTerminateVoltage(3200);  // Set your battery's cutoff voltage in mV
        FuelGauge_available = true;
    }

}

void loop(void) {

    // if D0 is pulled high through pull up -> go to sleep 
    if(digitalRead(D0) == HIGH){
      handle_Sleep();  
    }

    switch (currentState) {
        case STATE_STARTUP:
            handleStartup();
            break;

        case STATE_MAIN_MENU:
            handleMainMenu();
            break;

        case STATE_BRIGHTNESS_CONFIG:
            handleBrightnessConfig();
            break;

        case STATE_MODE_CONFIG:
            handleModeConfig();
            break;

        case STATE_STUDY_MODE:
            handleStudyMode();
            break;

        case STATE_BREAK_MODE:
            handleBreakMode();
            break;

        case STATE_BREAK_OVERFLOW:
            handleBreak_Overflow();
            break;
    }

    readPCA9536(); // check PCA9536 for magnet status and button press

    handleStatusLEDs(); // Update status LEDs based on current conditions

    delay(10);
}

void handle_Sleep() {
    // Turn off the LED ring before sleeping
    FastLED.clear();
    FastLED.show();

    // Turn off the load switch to cut power to peripherals
    digitalWrite(D6, LOW); // Ensure load switch is off

    Serial.println("In sleep condition - preparing to sleep");

    // Also turn off the status strip if you want
    fill_solid(status_leds, NUM_LEDS_STATUS, CRGB::Black);
    FastLED.show();
    Serial.println("delaying before sleep...");
    Serial.println("Going to sleep now");
    delay(5000);
    Serial.flush();  // Ensure all serial output is sent before sleeping
    esp_deep_sleep_start();
}

void handle_NVM(){

    preferences.begin("StudyTimer", false);
    
    brightness_bar_count = preferences.getInt("br_bar", brightness_bar_count);
    if(NVM_debug){
        Serial.print("Loaded brightness_bar_count from NVM: "); 
        Serial.println(brightness_bar_count);
    }
    if (brightness_bar_count < BRIGHTNESS_BAR_MIN || brightness_bar_count > BRIGHTNESS_BAR_MAX) {
        brightness_bar_count = 1;
    }
    brightness_limit = brightnessLevels[brightness_bar_count - 1];
    FastLED.setBrightness(brightness_limit);

    check_FixedStudy = preferences.getInt("mode_fix", check_FixedStudy);
    FixedStudy_Index = preferences.getInt("fix_index", FixedStudy_Index);
    if(NVM_debug){
        Serial.print("Loaded mode_fix (check_FixedStudy) from NVM: "); 
        Serial.println(check_FixedStudy);
        Serial.print("Loaded fix_index (FixedStudy_Index) from NVM: "); 
        Serial.println(FixedStudy_Index);
    }

}

void handleStatusLEDs() {

    // Status LED at index 2: audio status (orange if enabled, blue if disabled)
    if(enable_status_LED){
        CRGB color = audio_enabled ? CRGB::Orange : CRGB::Blue;
        //color.nscale8_video(40); // Scale down brightness for status LED
        status_leds[2] = color;
    } else {
        status_leds[2] = CRGB::Black;  // Keep it off if status LED is disabled
    }

    if(enable_status_LED){
        if(FuelGauge_available){
            int SoC = getFuelGaugeSOC();
            if(SoC > 60){
                CRGB battery_color = CRGB::Green;
                status_leds[0] = battery_color;
            }
            else if(SoC <= 60 && SoC > 20){
                CRGB battery_color = CRGB::Orange;
                status_leds[0] = battery_color;
            }
            else{
                CRGB battery_color = CRGB::Red;
                status_leds[0] = battery_color;
            }
        }
    } 
    else {
        status_leds[0] = CRGB::Black;  // Keep it off if status LED is disabled
    }


    FastLED.show();
}

void readPCA9536(void) {
    // Set IO0 as input
    Wire.beginTransmission(0x41);
    Wire.write(0x03); // Configuration register
    Wire.write(0x0F); // Set all bits to 1 (all inputs)
    Wire.endTransmission();

    // Read input port
    Wire.beginTransmission(0x41);
    Wire.write(0x00); // Input port register
    Wire.endTransmission(false);
    Wire.requestFrom(0x41, 1);

    if (Wire.available()) {
        byte input = Wire.read();
        magnet_detected = not(input & 0x01);  // Bit 0 = 0 means magnet detected (active low)
        audio_enabled = not(input & 0x02);  // Bit 1 = 0 means audio enabled (active low)
        right_click = not(input & 0x04);  // Bit 2 = 0 means right click detected (active low)
        left_click = not(input & 0x08);  // Bit 3 = 0 means left click detected (active low)
        if (Magnet_debug) {
            Serial.print("PCA9536 IO0: ");
            Serial.println(magnet_detected ? "magnet detected" : "no magnet");
            Serial.print("PCA9536 IO1: ");
            Serial.println(audio_enabled ? "audio enabled" : "audio disabled");
            Serial.print("PCA9536 IO2: ");
            Serial.println(right_click ? "right click detected" : "no right click");
            Serial.print("PCA9536 IO3: ");
            Serial.println(left_click ? "left click detected" : "no left click");
        }
    } else {
        if (Magnet_debug) {
            Serial.println("Failed to read from PCA9536");
        }
    }
}

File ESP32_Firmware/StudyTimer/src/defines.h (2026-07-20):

// defines.h file

#ifndef DEFINES_H
#define DEFINES_H

#include <Arduino.h>
#include <Wire.h>
#include "Adafruit_seesaw.h"
#include <FastLED.h>
#include "esp_sleep.h"
#include "SparkFunBQ27441.h"

// for saving to non-volatile storage
#include <Preferences.h>

#define LED_PIN 4
#define NUM_LEDS 24

#define PCF8574_I2C_ADDRESS 0x38

#define LED_PIN_STATUS 3
#define NUM_LEDS_STATUS 4

#define WAKEUP_GPIO GPIO_NUM_1    // Only RTC IO are allowed - ESP32 Pin example -> D0 Pin 

// for saving to non-volatile storage
extern Preferences preferences;

extern CRGB status_leds[];

// Declare globals (definitions will be in main.cpp)
extern CRGB leds[];
extern Adafruit_seesaw ss;
extern int32_t encoder_position;

extern bool magnet_detected;
extern bool audio_enabled;
extern bool right_click;
extern bool left_click;
extern int streak_counter; 

extern bool streak_enabled;

extern bool Main_Menu_debug;
extern bool Study_Mode_debug;
extern bool Break_Mode_debug;
extern bool Config_Menus_debug;
extern bool Startup_debug;
extern bool Magnet_debug;
extern bool FuelGauge_debug;
extern bool I2C_debug;
extern bool NVM_debug;
extern bool FuelGauge_available;

extern bool strict_mode;

// Global BQ27441 instance with default address 0x55
extern BQ27441 lipo;

// ... existing code ...

extern int brightness_limit;  // Max brightness (0-255)
const int fade_steps = 40;         // Number of fade steps
const int fade_delay_ms = 10;      // Delay between steps (20ms ≈ 0.02s)

extern bool breakStartupPlayed;

extern int brightness_bar_count;

extern const int brightnessLevels[];
extern const int brightnessLevelsCount;

extern bool enable_status_LED;
extern bool battery_is_high;
extern bool audio_on;

extern const int TONE_PIN;
extern const int TONE_CHANNEL;
extern const int TONE_FREQ;
extern const int TONE_RES;

#define BRIGHTNESS_BAR_MIN 1
#define BRIGHTNESS_BAR_MAX 5

extern bool check_FixedStudy;
extern int FixedStudy_Index;
extern unsigned long config_blink_start;
const float config_blink_period = 1.0;  // seconds
extern bool mode_config_entered;

// ... existing code ...

// ... existing code ...

// Study mode parameters
extern int time_per_block;  // Seconds per block (e.g., 150)
extern int study_counter;
extern int num_leds_lit;
extern unsigned long start_block_time;
extern bool study_started;

// Animation durations (seconds)
const float fade_up_duration = 1.0;
const float fade_down_duration = 0.5;
const float off_duration = 1.0;
const float total_anim_duration = fade_up_duration + fade_down_duration + off_duration;

// Fade steps for full reset
const int full_fade_steps = 20;
const int full_fade_delay_ms = 20;

extern int32_t encoder_offset;
extern int32_t last_position;
extern unsigned long encoder_last_activity;
const unsigned long ENCODER_IDLE_TIMEOUT = 10000;  // 10 seconds in ms

// ... existing code ...

// Break mode parameters
extern int time_per_block_break;  // Seconds per break block (e.g., 60)
extern int break_interval;
extern int current_led_index;
extern unsigned long break_start_block_time;
extern bool break_started;

// Break animation durations (seconds)
const float break_fade_down_duration = 1.0;
const float break_fade_up_duration = 0.5;
const float break_stay_on_duration = 1.0;
const float break_total_anim_duration = break_fade_down_duration + break_fade_up_duration + break_stay_on_duration;

// Add button state tracking for pressed/released detection (optional, for accuracy)
extern bool buttonStates[5];  // Track previous states for 5 buttons

const int CENTER_BUTTON = 5;
const int RIGHT_BUTTON = 3;
const int LEFT_BUTTON = 11;
const int UP_BUTTON = 0;
const int DOWN_BUTTON = 4;

// Color options (excluding white and green)
extern const CRGB colorOptions[];
extern const char* colorOptions_strings[];
extern const int numColors;
extern int currentColorIndex;  // Track which color is active

typedef enum {
    STATE_STARTUP,
    STATE_MAIN_MENU,
    STATE_BRIGHTNESS_CONFIG,
    STATE_MODE_CONFIG,
    STATE_STUDY_MODE,
    STATE_BREAK_MODE,
    STATE_BREAK_OVERFLOW,
} AppState_t;

extern AppState_t currentState;

#endif  // DEFINES_H

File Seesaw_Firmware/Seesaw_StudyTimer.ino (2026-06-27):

// example_pid5681_edit_StudyTimer.ino

#define PRODUCT_CODE            5681
#define CONFIG_I2C_PERIPH_ADDR  0x49
//#define CONFIG_UART_DEBUG         1

#define CONFIG_INTERRUPT_PIN        6
//#define USE_PINCHANGE_INTERRUPT   1

// Can have up to 3 addresses
#define CONFIG_ADDR_0_PIN          12
#define CONFIG_ADDR_1_PIN          13

//#define CONFIG_ADC                 1
//#define CONFIG_PWM                 1
//#define CONFIG_NEOPIXEL            1
//#define CONFIG_NEOPIXEL_BUF_MAX   (60*3) // 60 pixels == 180 bytes

#define CONFIG_ENCODER 1
#define CONFIG_NUM_ENCODERS 1
#define CONFIG_ENCODER0_A_PIN 1
#define CONFIG_ENCODER0_B_PIN 2

#define CONFIG_ENCODER_2TICKS 1


#include "Adafruit_seesawPeripheral.h"

void setup() {
#if CONFIG_UART_DEBUG
  Serial.begin(115200);
  delay(500);
#endif
  delay(1);
  Adafruit_seesawPeripheral_begin();
}


void loop() {
  Adafruit_seesawPeripheral_run();
}

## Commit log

2026-06-27 Create ESP32 Firmware
2026-06-27 ESP32 firmware from PlatformIO
2026-06-27 KiCAD files for BOTTOM
    [StudyTimer_v1.2_Bottom.kicad_pcb, StudyTimer_v1.2_Bottom.kicad_sch]
2026-06-27 KiCAD files for TOP
    [StudyTimer_v1.2_Top.kicad_pcb, StudyTimer_v1.2_Top.kicad_sch]
2026-06-27 BOM files
2026-06-27 Gerber files for TOP and BOT board
2026-06-27 STL files for 3D printing
    [Bottom.stl, Diffuser.stl, Magnet_White.stl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]
